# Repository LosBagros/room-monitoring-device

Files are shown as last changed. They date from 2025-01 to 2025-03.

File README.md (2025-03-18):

# Room monitoring device

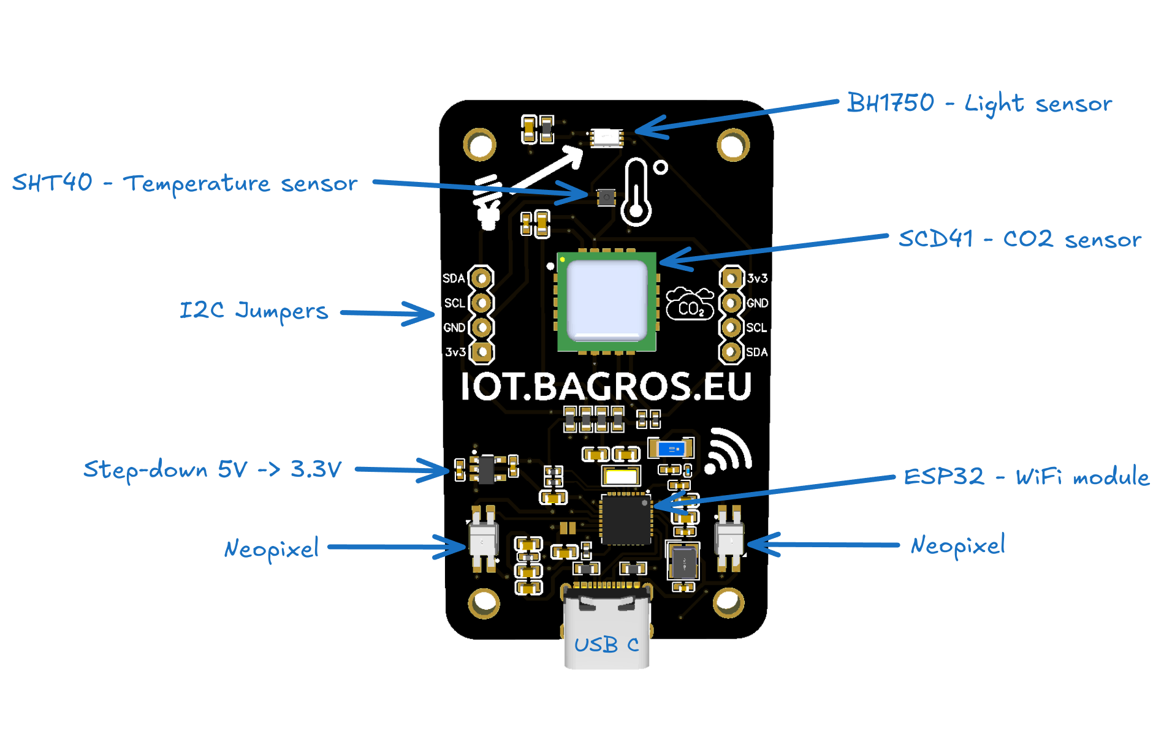
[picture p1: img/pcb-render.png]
Room monitoring device


## Used parts

- ESP32 - microcontroller
- SHT40 - temperature and humidity
- BH1750 - light
- SCD40 - CO2, temperature and humidity

## Schematic

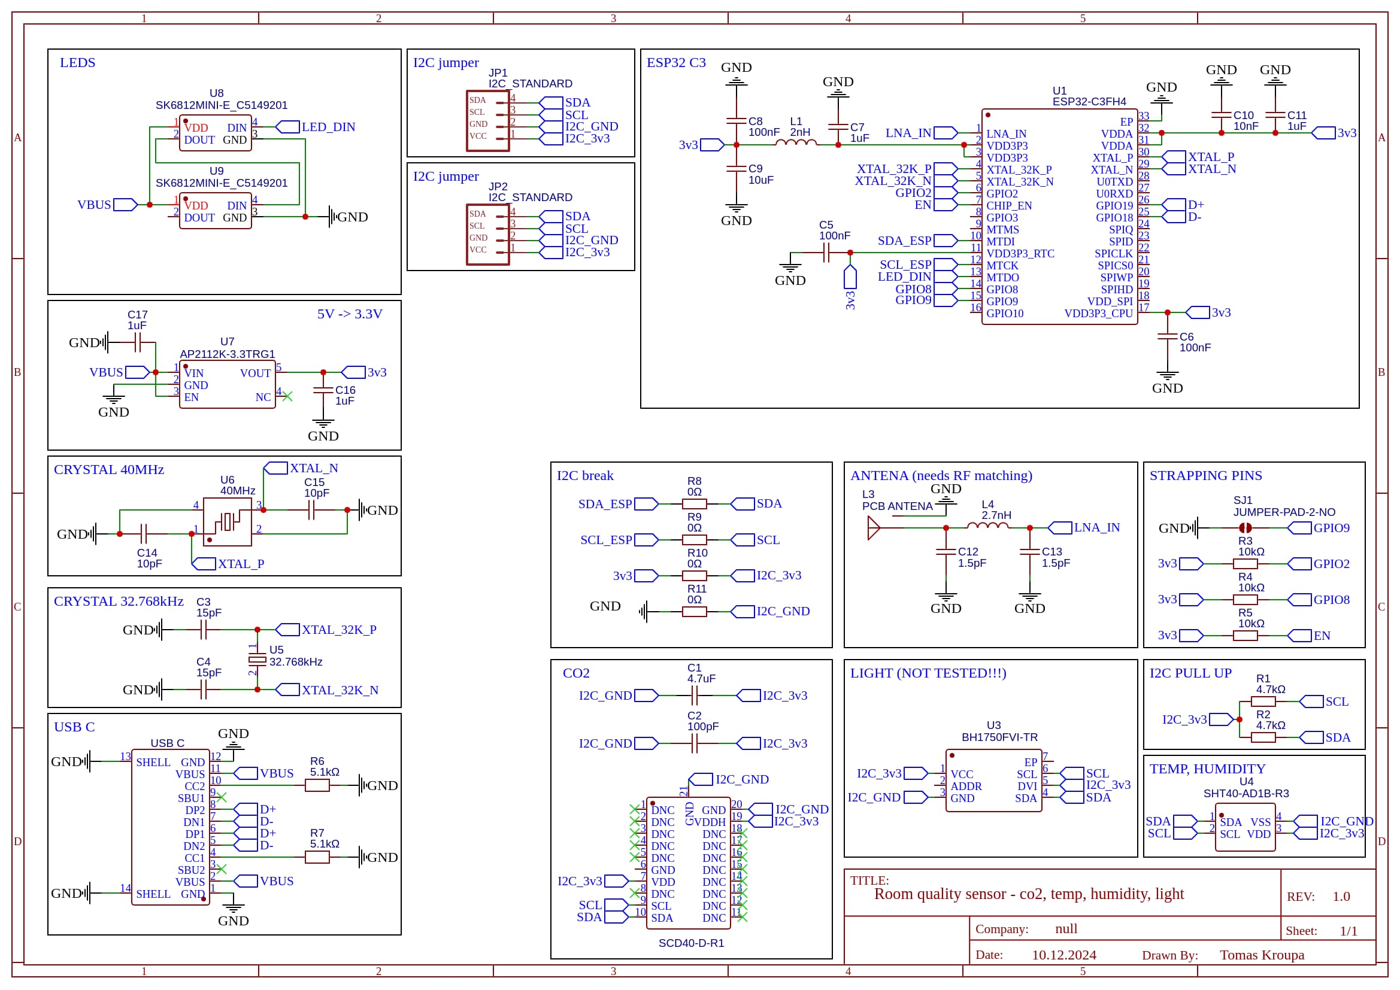
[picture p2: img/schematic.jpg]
Schematic


## Manufacturing

**⚠️ Warning: Do not manufacture my PCB design. Step-down and ESP is heating the board resulting with wrong temperature measurement. There are some issues with RF matching resulting in weak wifi connection. PCB should to be redesigned in future!**

If you still want to manufacture it. Just upload content of `pcb` folder to your favorite PCB manufacturer. I used [JLCPCB](https://jlcpcb.com/).

## Programming

1. Install [PlatformIO](https://platformio.org/) extension for your favorite IDE.
2. Clone this repository.
3. Open this project in your IDE.
4. Rename `src/secret.example.h` to `src/secret.h`
5. Fill in mqtt credentials and sensor id.
6. Connect board to your computer.
7. Build and upload project to your board.
8. Done. LEDs should light up.

Sensor sends data over MQTT. It's in separate [repository](https://github.com/LosBagros/iot-platform).

## Manuals

- [CZ manual](manual_cz.md)
- [EN manual](manual.md)

## Case

3D Case was designed by [Jakub Lips](https://www.instagram.com/__li_po_/)

## Images

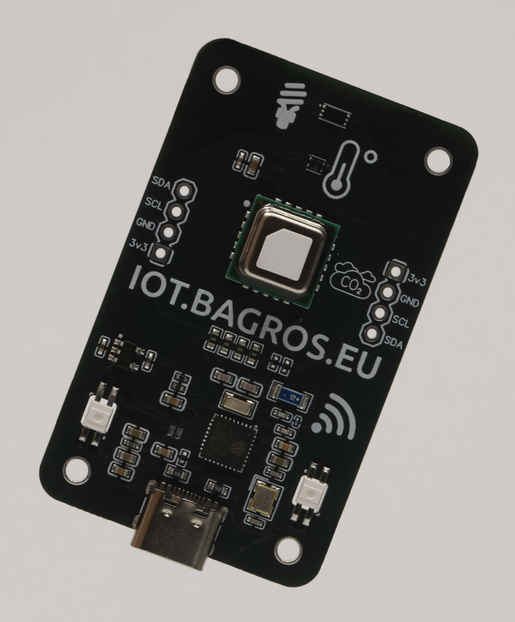
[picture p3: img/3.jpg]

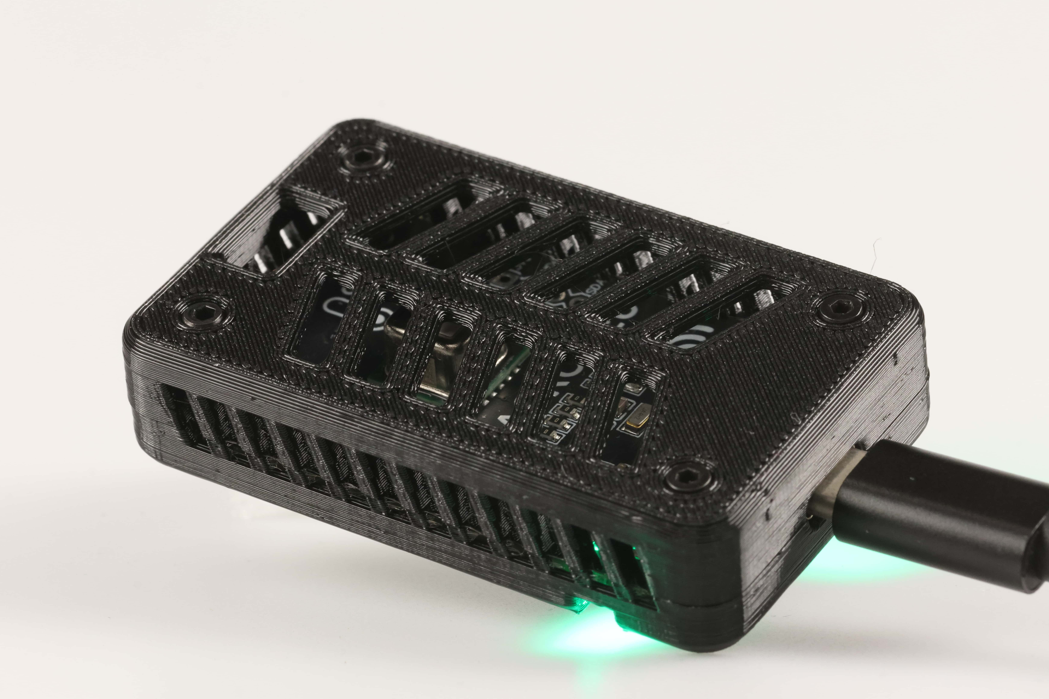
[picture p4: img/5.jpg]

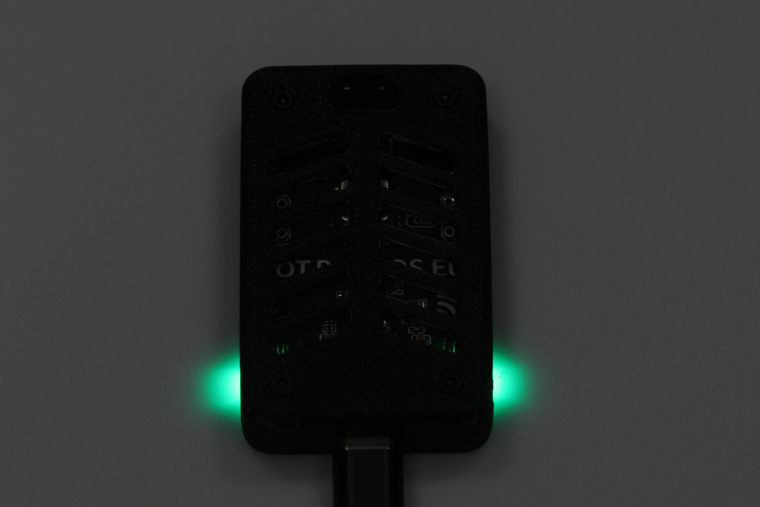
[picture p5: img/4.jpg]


## SVG Sources

- https://www.svgrepo.com/svg/473423/temperature-half - MIT
- https://www.svgrepo.com/svg/236180/co2 - CC0
- https://www.svgrepo.com/svg/479509/light-bulb - Public Domain
- https://www.svgrepo.com/svg/162992/mall-wifi-sign - CC0
- https://www.svgrepo.com/svg/64380/diagonal-arrow - CC0

[Tabler icons](https://tabler.io/icons/)

- microwave-off
- bucket-droplet
- flame
- bolt
- gavel
- paw-off

## License

[WTFPL](./LICENSE)

Libraries used in this project are licensed under their respective licenses.

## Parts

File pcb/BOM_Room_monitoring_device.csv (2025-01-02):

ID | Name | Designator | Footprint | Quantity | Manufacturer Part | Manufacturer | Supplier | Supplier Part | Price | Pins | Contributor | JLCPCB Part Class | description
1 | 4.7uF | C1 | C0603 | 1 | CL10A475KP8NNNC | SAMSUNG(三星) | LCSC | C1705 | 0.004 | 2 |  | Extended Part
2 | 100pF | C2 | C0402 | 1 | C1005C0G1H101JT000F | TDK | LCSC | C445763 | 0.008 | 2 | LCSC | Extended Part
3 | 15pF | C3,C4 | C0603 | 2 | CL10C150JB8NNNC | SAMSUNG(三星) | LCSC | C1644 | 0.005 | 2 |  | Basic Part
4 | 100nF | C5,C6,C8 | C0603 | 3 | CC0603KRX7R9BB104 | YAGEO(国巨) | LCSC | C14663 | 0.002 | 2 |  | Basic Part
5 | 1uF | C7,C11 | C0603 | 2 | CL10A105KB8NNNC | SAMSUNG(三星) | LCSC | C15849 | 0.004 | 2 |  | Basic Part
6 | 10uF | C9 | C0603 | 1 | CL10A106MP8NNNC | SAMSUNG(三星) | LCSC | C85713 | 0.005 | 2 |  | Extended Part
7 | 10nF | C10 | C0603 | 1 | 0603B103K500NT | FH(风华) | LCSC | C57112 | 0.002 | 2 |  | Basic Part
8 | 1.5pF | C12,C13 | C0402 | 2 | CC0402BRNPO9BN1R5 | YAGEO(国巨) | LCSC | C282238 | 0.002 | 2 | LCSC | Extended Part
9 | 10pF | C14,C15 | C0402 | 2 | CL05C100JB5NNNC | SAMSUNG(三星) | LCSC | C32949 | 0.005 | 2 |  | Basic Part
10 | 1uF | C16,C17 | C0402 | 2 | CL05A105KP5NNNC | SAMSUNG(三星) | LCSC | C14445 | 0.002 | 2 |  | Extended Part
11 | I2C_STANDARD | JP1,JP2 | 1X04 | 2 |  |  |  |  |  | 4 | SparkFun |  | SparkFun has standardized on a pinout for all I2C based sensor breakouts.
12 | 2nH | L1 | L0402 | 1 | CLH1005T-2N0S-S-NP | chilisin(奇力新) | LCSC | C142239 | 0.004 | 2 |  | Extended Part
13 | PCB ANTENA | L3 | ANT-SMD_L3.1-W1.6 | 1 | KH-RFECA3216060A1T_V09 | kinghelm(金航标) | LCSC | C411566 | 0.062 | 2 | LCSC | Extended Part
14 | 2.7nH | L4 | L0201 | 1 | LQP03TN2N7B02D | muRata(村田) | LCSC | C98043 | 0.004 | 2 |  | Extended Part
15 | 4.7kΩ | R1,R2 | R0402 | 2 | 0402WGF4701TCE | UNI-ROYAL(厚声) | LCSC | C25900 | 0.001 | 2 |  | Basic Part
16 | 10kΩ | R3,R4,R5 | R0402 | 3 | 0402WGF1002TCE | UNI-ROYAL(厚声) | LCSC | C25744 | 0.001 | 2 |  | Basic Part
17 | 5.1kΩ | R6,R7 | R0603 | 2 | FRC0603J512 TS | FOJAN(富捷) | LCSC | C2907114 | 0.001 | 2 | lcsc | Extended Part
18 | 0Ω | R8,R9,R10,R11 | R0603 | 4 | 0603WAF0000T5E | UNI-ROYAL(厚声) | LCSC | C21189 | 0.001 | 2 |  | Basic Part
19 | JUMPER-PAD-2-NO | SJ1 | PAD-JUMPER-2-NO_NO_SILK | 1 |  |  |  |  |  | 2 | SparkFun
20 | ESP32-C3FH4 | U1 | QFN-32_L5.0-W5.0-P0.50-TL-EP3.7 | 1 | ESP32-C3FH4 | ESPRESSIF(乐鑫) | LCSC | C2858491 | 2.291 | 33 | LCSC | Extended Part
21 | SCD40-D-R1 | U2 | LGA-20_L10.1-W10.1-P1.25-TL | 1 | SCD40-D-R1 | Sensirion(瑞士盛思锐) | LCSC | C3037696 |  | 21 | lcsc | Extended Part
22 | BH1750FVI-TR | U3 | WSOF-6_L2.6-W1.6-P0.50-TL-EP | 1 | BH1750FVI-TR | ROHM(罗姆) | LCSC | C78960 | 0.821 | 7 |  | Extended Part
23 | SHT40-AD1B-R3 | U4 | DFN-4_L1.5-W1.5-P0.8-TL-EP | 1 | SHT40-AD1B-R3 | Sensirion(瑞士盛思锐) | LCSC | C2848306 |  | 5 | LCSC | Extended Part
24 | 32.768kHz | U5 | CRYSTAL-SMD_L3.2-W1.5-1 | 1 | H31003271C2070CY | JGHC(晶光华) | LCSC | C5361379 | 0.137 | 2 | lcsc | Extended Part
25 | 40MHz | U6 | CRYSTAL-SMD_4P-L3.2-W2.5-BL | 1 | L327S400H11L | Lucki(蓝晶) | LCSC | C5261245 | 0.066 | 4 | lcsc | Extended Part
26 | AP2112K-3.3TRG1 | U7 | SOT-25-5_L2.9-W1.6-P0.95-LS2.8-BL | 1 | AP2112K-3.3TRG1 | DIODES(美台) | LCSC | C51118 | 0.064 | 5 | LCSC | Extended Part
27 | SK6812MINI-E_C5149201 | U8,U9 | LED-SMD_L3.2-W2.8-TR | 2 | SK6812MINI-E | 欧思科光电 | LCSC | C5149201 | 0.076 | 4 | lcsc | Extended Part
28 | USB C | USB | USB-C-SMD_TYPE-C-6PIN-2MD-073 | 1 | TYPE-C 16PIN 2MD(073) | SHOU HAN(首韩) | LCSC | C2765186 | 0.053 | 14 | LCSC | Extended Part

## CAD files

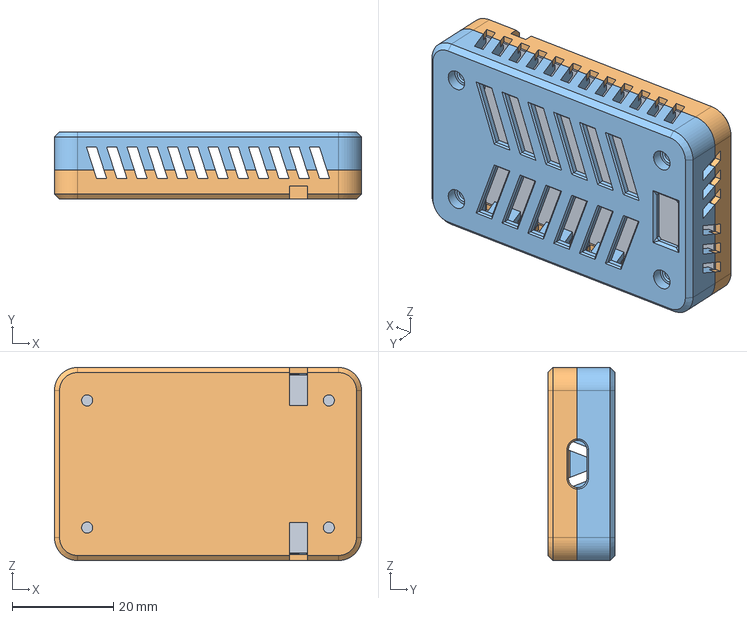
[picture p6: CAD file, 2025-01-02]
3d/case_v4.step
60.6 x 13.3 x 38.1 mm

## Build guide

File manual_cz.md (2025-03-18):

# Manuál zařízení pro monitorování místnosti

Odkaz na [Anglickou verzi](manual.md)

Postup pro instalaci a používání zařízení **Room Monitoring Device**, které měří **koncentraci CO₂**, **teplotu** a **vlhkost vzduchu** v místnosti.

## ⚠️ Důležité bezpečnostní upozornění

> **Nenechávejte zařízení bez dozoru.**
>
> Ačkoli bylo zařízení v praxi stabilní a spolehlivé, **jedná se o vlastní elektronické zařízení a nelze zcela vyloučit poruchu nebo riziko požáru**.
>
> Vždy umisťujte zařízení na **nehořlavý povrch**, držte jej **mimo dosah hořlavých materiálů** a **pravidelně kontrolujte jeho provoz**.
>
> **Používejte pouze 5V napájecí adaptéry.**

## Pokyny pro instalaci

### 1. Napájení

- Použijte stabilní 5V USB-C napájecí zdroj (např. nabíječka pro mobilní telefon).
- Zajistěte nepřerušované napájení pro spolehlivý provoz a přenos dat.

### 2. Připojení k Wi-Fi

- Umístěte zařízení blízko Wi-Fi routeru, aby bylo zajištěno silné a stabilní připojení. Nejlépe ve stejné místnosti jako je router.
- Ujistěte se, že vaše Wi-Fi síť funguje na frekvenci 2.4 GHz. Zařízení nepodporuje 5 GHz sítě.
- Po zapnutí zařízení vytvoří vlastní Wi-Fi síť s názvem `RoomMonitorAP` a heslem `12345678`.
- Připojte se k této síti a otevřete prohlížeč na adrese `http://192.168.4.1`.
- Zadejte název vaší Wi-Fi sítě (SSID) a heslo pro připojení zařízení do vaší domácí sítě.

### 3. Doporučené umístění

- Umístěte zařízení mimo:
  - Přímého slunečního světla
  - Topných nebo chladicích jednotek
  - Oken a dveří
- Zajistěte volný proud vzduchu kolem zařízení — neumisťujte jej do uzavřených prostor.

## Známé problémy

- Měření teploty a vlhkosti z PCB je ovlivněno zahříváním desky, což vede k nepřesným hodnotám.
- Senzor světla nefunguje v této verzi PCB kvůli chybě v návrhu schématu.
- Wi-Fi anténa je slabá, což může vést k nestabilnímu připojení, pokud je zařízení daleko od routeru.

## Online Dashboard

[**IOT.BAGROS.EU**](https://iot.bagros.eu/d/be7hw0wxuy1vkc/co2?orgId=1&from=now-3h&to=now&timezone=browser&kiosk)

Dashboard zobrazuje:

- **Koncentraci CO₂ (ppm)**
- **Teplotu místnosti (°C)**
- **Relativní vlhkost vzduchu (%)**

## LED Indikace

| Barva LED | Hladina CO₂ (ppm) | Akce |
| --- | --- | --- |
| 🟢 Dobrá | `< 1000 ppm` | Není potřeba žádná akce |
| 🟡 Střední | `1000 - 2000 ppm` | Zvýšit větrání |
| 🔴 Špatná | `> 2000 ppm` | Okamžitě zlepšit větrání |
| 🔵 Senzor nepřipraven | `N/A` | Čekání na zahřátí CO₂ senzoru |
| ⚪ Není připojeno k WiFi | `N/A` | WiFi není nakonfigurováno nebo připojeno |

## Varování

<!-- prettier-ignore-start -->
<!-- markdownlint-disable -->
<table>
    <tr>
        <td align="center">
            Mikrovlnná trouba ikona
            <br />
            <sub><b>Nedávejte zařízení do mikrovlnné trouby</b></sub>
        </td>
        <td align="center">
            Voda ikona
            <br />
            <sub><b>Nevystavujte vodě</b></sub>
        </td>
        <td align="center">
            Hořlavé materiály ikona
            <br />
            <sub><b>Nepokládejte blízko hořlavých materiálů</b></sub>
        </td>
    </tr>
    <tr>
        <td align="center">
            Kladivo ikona
            <br />
            <sub><b>Netestujte odolnost kladivem</b></sub>
        </td>
        <td align="center">
            Napájení ikona
            <br />
            <sub><b>Nepoužívejte jiný zdroj napájení než 5V</b></sub>
        </td>
        <td align="center">
            Zvířata ikona
            <br />
            <sub><b>Nepovolujte domácím mazlíčkům monitorovat vzduch</b></sub>
        </td>
    </tr>
</table>
<!-- markdownlint-restore -->
<!-- prettier-ignore-end -->

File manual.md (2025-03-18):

# Room Monitoring Device Manual

Link to [Czech version](manual_cz.md)

This document provides setup instructions and usage guidelines for the **Room Monitoring Device**, which continuously measures **CO₂ concentration**, **temperature**, and **humidity** in indoor environments.

## ⚠️ Important Safety Notice

> **Do not leave the device unattended.**
>
> Although the device has been stable and reliable in practice, **it is a custom electronic device and there is no absolute guarantee against hardware failure or fire risk**.
>
> Always place the device on a **non-flammable surface**, keep it **away from flammable materials**, and **periodically monitor its operation**.
>
> **Use only 5V power adapters**

## Setup Instructions

### 1. Power Supply

- Use a stable 5V USB-C power source (standard phone charger with USB-C output).
- Ensure uninterrupted power for continuous monitoring and reliable data transmission.

### 2. Wi-Fi Connectivity

- Place the device close to your Wi-Fi router to ensure strong and stable signal strength. Ideally in the same room as the router.
- Ensure your Wi-Fi network operates on the 2.4 GHz band. The device does not support 5 GHz Wi-Fi networks.
- When first powered on, the device will create a Wi-Fi hotspot named `RoomMonitorAP` with password `12345678`.
- Open captive portal by connecting to the hotspot and visiting `http://192.168.4.1` in a web browser.
- Enter your Wi-Fi SSID and password to connect the device to your Wi-Fi network.

### 3. Placement Recommendations

- Position the device at typical room height, away from:
  - Direct sunlight
  - Heating/cooling vents
  - Windows and doors
- Avoid enclosing the device in tight spaces to allow free airflow around the sensors.

## Known Issues

- Temperature and humidity measurements from the PCB are affected by board self-heating, leading to inaccurate readings.
- The light sensor does not work in this PCB version due to a schematic design mistake.
- Wi-Fi antenna is weak, which may result in unstable connectivity if the device is far from the router.

## Live Dashboard

[**IOT.BAGROS.EU**](https://iot.bagros.eu/d/be7hw0wxuy1vkc/co2?orgId=1&from=now-3h&to=now&timezone=browser&kiosk)

The dashboard provides:

- **CO₂ concentration (ppm)**
- **Room temperature (°C)**
- **Relative humidity (%)**

## LED Indicator

| LED Color | CO₂ Level (ppm) | Action |
| --- | --- | --- |
| 🟢 Good | `< 1000 ppm` | No action needed |
| 🟡 Moderate | `1000 - 2000 ppm` | Increase ventilation |
| 🔴 Poor | `> 2000 ppm` | Immediately improve ventilation |
| 🔵 Sensor not ready | `N/A` | Waiting for CO₂ sensor to warmup |
| ⚪ Not connected to wifi | `N/A` | Wifi is not configured / connected |

## DO NOT

<!-- prettier-ignore-start -->
<!-- markdownlint-disable -->
<table>
    <tr>
        <td align="center">
            Microwave icon
            <br />
            <sub><b>Do not microwave the device</b></sub>
        </td>
        <td align="center">
            Water icon
            <br />
            <sub><b>Do not expose to water</b></sub>
        </td>
        <td align="center">
            Flammable icon
            <br />
            <sub><b>Do not place near flammable materials</b></sub>
        </td>
    </tr>
    <tr>
        <td align="center">
            Hammer
            <br />
            <sub><b>Do not test durability with a hammer</b></sub>
        </td>
        <td align="center">
            Power icon
            <br />
            <sub><b>Do not use a power source other than 5V</b></sub>
        </td>
        <td align="center">
            Power icon
            <br />
            <sub><b>Do not let pets monitor the air	</b></sub>
        </td>
    </tr>
</table>
<!-- markdownlint-restore -->
<!-- prettier-ignore-end -->

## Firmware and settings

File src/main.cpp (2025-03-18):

// TODO: Change LED behavior
#include <BH1750.h>            // https://github.com/claws/BH1750
#include <Adafruit_NeoPixel.h> // https://github.com/adafruit/Adafruit_NeoPixel
#include <Arduino.h>
#include <SensirionI2CScd4x.h> // https://github.com/Sensirion/arduino-i2c-scd4x
#include "Adafruit_SHT4x.h"    // https://github.com/adafruit/Adafruit_SHT4X
#include <WiFi.h>
#include <PubSubClient.h> // https://github.com/knolleary/PubSubClient
#include <ArduinoJson.h>  // https://github.com/bblanchon/ArduinoJson
#include <Wire.h>
#include <SPI.h>
#include <WiFiManager.h> //https://github.com/hraph/ESP32WiFiManager/ WiFi Configuration Magic

#include <secret.h>

#define DEV_BOARD // comment if using custom PCB

#ifdef DEV_BOARD
#define LED_PIN 8
#define NUMPIXELS 1
#define SDA 2
#define SCL 1
#else
#define LED_PIN 7
#define NUMPIXELS 2
#define SDA 5
#define SCL 6
#endif

char mqttTopic[50];

WiFiClient espClient;
PubSubClient mqttClient(espClient);

Adafruit_NeoPixel strip = Adafruit_NeoPixel(NUMPIXELS, LED_PIN, NEO_GRB + NEO_KHZ800);
Adafruit_SHT4x sht4 = Adafruit_SHT4x();
SensirionI2CScd4x scd4x;
#ifdef DEV_BOARD
BH1750 lightMeter;
#endif

void setColor(uint8_t r, uint8_t g, uint8_t b)
{
  for (int i = 0; i < NUMPIXELS; i++)
  {
    strip.setPixelColor(i, strip.Color(r, g, b));
  }
  strip.show();
}

int mqttTries = 0;
void connectToMQTTBroker()
{
  mqttTries = 0;
  while (!mqttClient.connected())
  {
    Serial.print("Connecting to MQTT...");
    mqttClient.setServer(mqttServer, mqttPort);
    if (mqttClient.connect(sensorId, mqttUser, mqttPassword))
    {
      Serial.println("connected");
    }
    else
    {
      Serial.print(" failed with state ");
      Serial.println(mqttClient.state());
      delay(2000);
    }
    mqttTries++;
    if (mqttTries > 30)
    {
      ESP.restart();
    }
  }
}

void setup()
{
  Serial.begin(115200);
  strip.begin();
  setColor(10, 10, 10);

  WiFi.mode(WIFI_STA);

#ifndef DEV_BOARD
  WiFi.setTxPower(WIFI_POWER_5dBm);
#endif

  WiFiManager wm;

  bool res;
  res = wm.autoConnect("RoomMonitorAP", "12345678"); // password protected ap
  if (!res)
  {
    Serial.println("Failed to connect");
  }

  Wire.begin(SDA, SCL);

#ifdef DEV_BOARD
  lightMeter.begin();
#endif

  if (!sht4.begin())
  {
    while (1)
    {
      Serial.println("Couldn't find SHT4x");
      delay(1000);
    }
  }
  sht4.setPrecision(SHT4X_HIGH_PRECISION);
  sht4.setHeater(SHT4X_NO_HEATER);

  scd4x.begin(Wire);
  uint16_t error;
  char errorMessage[256];

  error = scd4x.stopPeriodicMeasurement();
  if (error)
  {
    Serial.print("Error trying to execute stopPeriodicMeasurement(): ");
    errorToString(error, errorMessage, 256);
    Serial.println(errorMessage);
  }

  error = scd4x.startPeriodicMeasurement();
  if (error)
  {
    Serial.print("Error trying to execute startPeriodicMeasurement(): ");
    errorToString(error, errorMessage, 256);
    Serial.println(errorMessage);
  }
  strncpy(mqttTopic, mqttTopicBase, sizeof(mqttTopic) - 1);
  strncat(mqttTopic, sensorId, sizeof(mqttTopic) - 1);
}

sensors_event_t hum, temp;
uint32_t timestamp = 0;
uint16_t co2 = 0;
float co2Temperature = 0.0f;
float co2Humidity = 0.0f;
uint16_t error = 0;
char errorMessage[256];
bool isDataReady = false;
float lux = 0;

StaticJsonDocument<256> jsonDoc;

void loop()
{
  hum.relative_humidity = 0.0f;
  temp.temperature = 0.0f;
  timestamp = 0;
  co2 = 0;
  co2Temperature = 0.0f;
  co2Humidity = 0.0f;
  error = 0;
  isDataReady = false;

  error = scd4x.getDataReadyFlag(isDataReady);
  if (error)
  {
    Serial.print("Error trying to execute getDataReadyFlag(): ");
    errorToString(error, errorMessage, 256);
    Serial.println(errorMessage);
    Serial.println();
    delay(1000);
    return;
  }
  if (!isDataReady)
  {
    Serial.println("Data not ready yet");
    setColor(0, 0, 100);
    delay(1000);
    return;
  }

  error = scd4x.readMeasurement(co2, co2Temperature, co2Humidity);
  if (error)
  {
    Serial.print("Error trying to execute readMeasurement(): ");
    errorToString(error, errorMessage, 256);
    Serial.println(errorMessage);
  }
  else
  {
    Serial.print("Co2: ");
    Serial.print(co2);
    Serial.print("\t");
    Serial.print("Temperature: ");
    Serial.print(co2Temperature);
    Serial.print("C ");
    Serial.print("Humidity: ");
    Serial.print(co2Humidity);
    Serial.print("%");
  }
  Serial.println();

  timestamp = millis();
  sht4.getEvent(&hum, &temp);
  timestamp = millis() - timestamp;

  Serial.print("Temperature: ");
  Serial.print(temp.temperature);
  Serial.print("C ");
  Serial.print("Humidity: ");
  Serial.print(hum.relative_humidity);
  Serial.print("% ");
  Serial.print(" Read duration (ms): ");
  Serial.print(timestamp);
  Serial.println();
#ifdef DEV_BOARD
  lux = lightMeter.readLightLevel();
  Serial.print("Light: ");
  Serial.print(lux);
  Serial.println(" lx");
  Serial.println();

#endif

  if (co2 > 2000)
  {
    setColor(100, 0, 0);
  }
  else if (co2 > 1000)
  {
    setColor(100, 50, 0);
  }
  else if (co2 < 1000 && co2 > 1)
  {
    setColor(0, 100, 0);
  }
  if (co2 <= 0)
  {
    Serial.println("CO2 Reading failed");
    return;
  }

  if (!mqttClient.connected())
  {
    connectToMQTTBroker();
  }

#ifdef DEV_BOARD
  jsonDoc["light"] = round(lux * 100) / 100.0;
#endif
  jsonDoc["temperature"] = round(temp.temperature * 100) / 100.0;
  jsonDoc["humidity"] = round(hum.relative_humidity * 100) / 100.0;
  jsonDoc["co2"] = co2;
  jsonDoc["co2_temperature"] = round(co2Temperature * 100) / 100.0;
  jsonDoc["co2_humidity"] = round(co2Humidity * 100) / 100.0;

  char jsonBuffer[256];
  serializeJson(jsonDoc, jsonBuffer);

  mqttClient.publish(mqttTopic, jsonBuffer);
  mqttClient.loop();
  delay(10000);
}

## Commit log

2025-01-02 update warning formatting in README.md for PCB design
2025-03-15 added lasercut
